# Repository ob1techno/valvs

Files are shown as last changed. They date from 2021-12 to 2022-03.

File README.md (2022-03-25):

# Vālvs
A cascading quad tube VCA module in Eurorack format (3U/32hp).

Vālvs provides four gnarly tube VCAs with drive, gain, feedback, and adjustable, switchable distortion controls.

Vālvs’ outputs are daisy-chained, allowing adjacent groups of 2, 3, or all 4 channels to be mixed together.

Vālvs v1.01 Stealth Mode

Based on/inspired by the work of [Ken Stone](https://www.elby-designs.com/webtek/cgs/cgs65/cgs65_vca.html), [L-1](http://l-1.su/TubeVCA.html) and [Émilie Gillet](https://mutable-instruments.net/modules/veils/), using NOS Soviet 1Ж24Б tubes; as used in the Спутник 1 satellite and Восток 1 spacecraft!

## Demos
#### Single channel audio demo
Vālvs - Quad Tube VCA - Single channel audio demo (https://www.youtube.com/watch?v=XpYaYiyOpng "Vālvs - Quad Tube VCA - Single channel audio demo")

#### Mixer demo
Vālvs - Quad Tube VCA - Mixer demo (https://www.youtube.com/watch?v=zRkru6GmQA4 "Vālvs - Quad Tube VCA - Mixer demo")

## [Build Guide](https://github.com/ob1techno/valvs/wiki/Vālvs-Build-Guide) 
The [build guide](https://github.com/ob1techno/valvs/wiki/Vālvs-Build-Guide) is available [in the wiki](https://github.com/ob1techno/valvs/wiki/Vālvs-Build-Guide).

## Notes

### Calibration/Adjustment
There are no hard and fast rules here. The module is intended to be pretty flexible in terms of gain/distortion so it's very much a case of setting it up to your own taste. You could calibrate each of the 4 VCAs as closely as possible to each other to keep things consistent or you could set each up to have a different character/flavour. 

Each VCA has 4 trimmers on the back of the PCB:

- Plate; this adjusts the plate resistance between 8.2k and 28.2k, which affects the overall gain of the VCA
- CV Init; this adjusts the initial gain voltage, which can be trimmed to ensure the VCA closes completely
- Clean; adjusts the amount of distortion for the "Clean" mode ("Clean" is a relative term in this case)
- Dist; adjusts the amount of distortion for the "Dirty" mode

It's _fairly_ important to get the CV Init trimmed correctly to avoid any audible bleed, but other than that, it's down to taste. You shoud be aware that with additional gain/distortion, there will be inevitable additional noise, so experiment to find the sweet spots.

### Noise
This is inherently a pretty noisy circuit. The tubes can be a little microphonic (this can be improved a little by mounting with some foam/padding between tube and board). The LEDs in Ken Stone's original design injected some more noise as they were connected to the tube's cathode which is in the signal path. L-1's design removes the LEDs, replacing with a 1/2W resistor to ground. 

I've built the circuit both ways and L-1's design is definitely less noisy. I originally thought I preferred the sound with the LEDs, but with all four VCAs mixed, the noise is too noticable, so I've gone with a resistor to ground! I've kept the LEDs to light the tubes, but these are now powered separately, away from the signal path. Even so, these are still quite noisy VCAs, though I prefer the term characterful!

### KiCad Components

I used some KiCad components/footprints that you might need to install if you want to edit the PCB files. You can find those here:
- [EuroCad](https://github.com/nebs/eurocad)
- [E-Switch](https://www.snapeda.com/parts/100SP1T1B4M2QE/E-Switch/view-part/)

### Parts/Construction
I selected parts for this module based on several factors; what I had in stock already, parts I am familiar with and like to use, availability, etc. This means it may not be the easiest module for some to build. For example, I've used 0603 passives, where I could probably have fit a larger size, or used through-hole components. I made this decision because I have a large stock of 0603 passives and I personally prefer SMT to THT. That said, I don't think this is a difficult build. I've built a few of them and it's a relatively low part count per VCA, so quite quick to put together. The surface mount components used also make this suitable for SMD fabrication/assembly services, which I have used successfully on my latest builds.

The construction should all be self explanatory as it's just a single board. Parts go on the side where their silkscreen is (although if you used particularly tall film box caps, you might need to move them to the back). 

There's also the option of mounting the trimmers for the clean/dirty distortion on the front of the PCB and drilling holes so they're adjustable from the front, if you like that sort of thing. 

It's worth using some heatshrink on the tube legs for peace of mind, though not strictly necessary, and I like to use some acetate sheet to fill the windows in case of dust, stray cables, etc.

[There are some build photos in the wiki.](https://github.com/ob1techno/valvs/wiki/Vālvs-Build-Guide)

### Disclaimer
I am not an electronic engineer. I am a musician/programmer with a keen interest in synthesis and electronics. I am entirely self-taught; this was my first project using KiCad and I'm sure I have made many mistakes. 

I have tried to ensure that this works before publishing my work, but this is presented as-is and with no guarantees or acceptance of responsibility on my part. I'd welcome any feedback and I am interested in improving the design; please use the issues section or submit a pull request. 

I also make no promises to support this project, but do get in touch and I'll help if I can.

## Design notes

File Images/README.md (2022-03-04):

## Images

### "OG" unit

Vālvs v1.01 Front

---

### "Stealth" unit

Vālvs v1.01 Stealth Mode

---

### Panel design

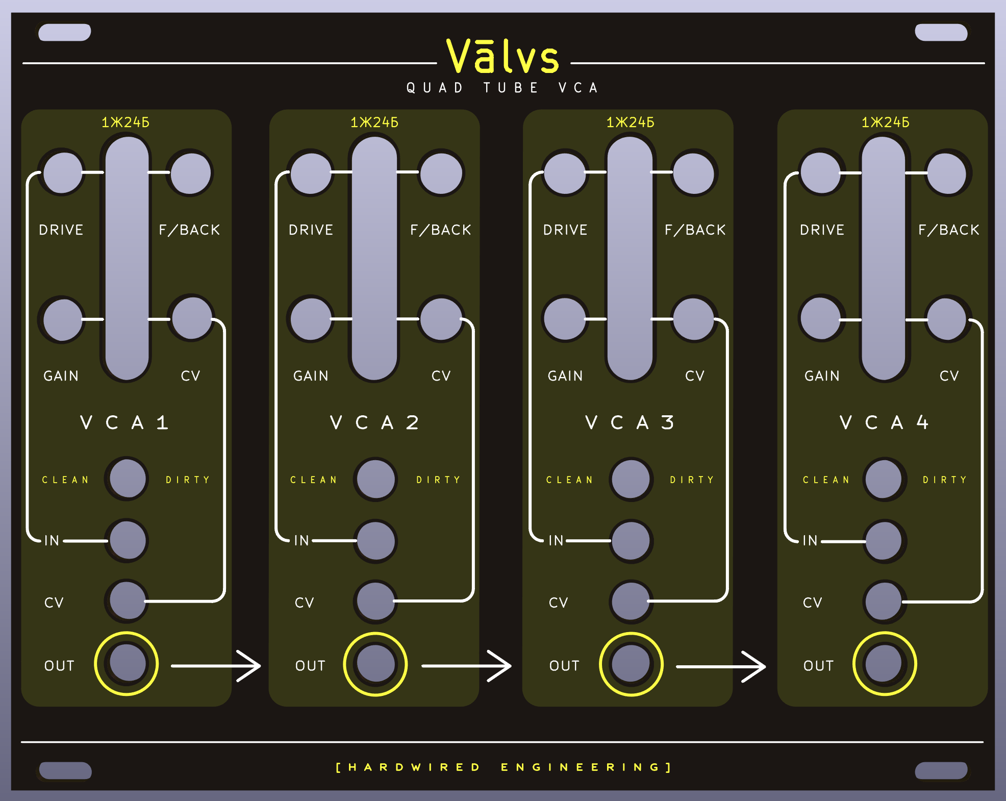
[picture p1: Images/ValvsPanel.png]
Prototype Panel


---

### PCB front 

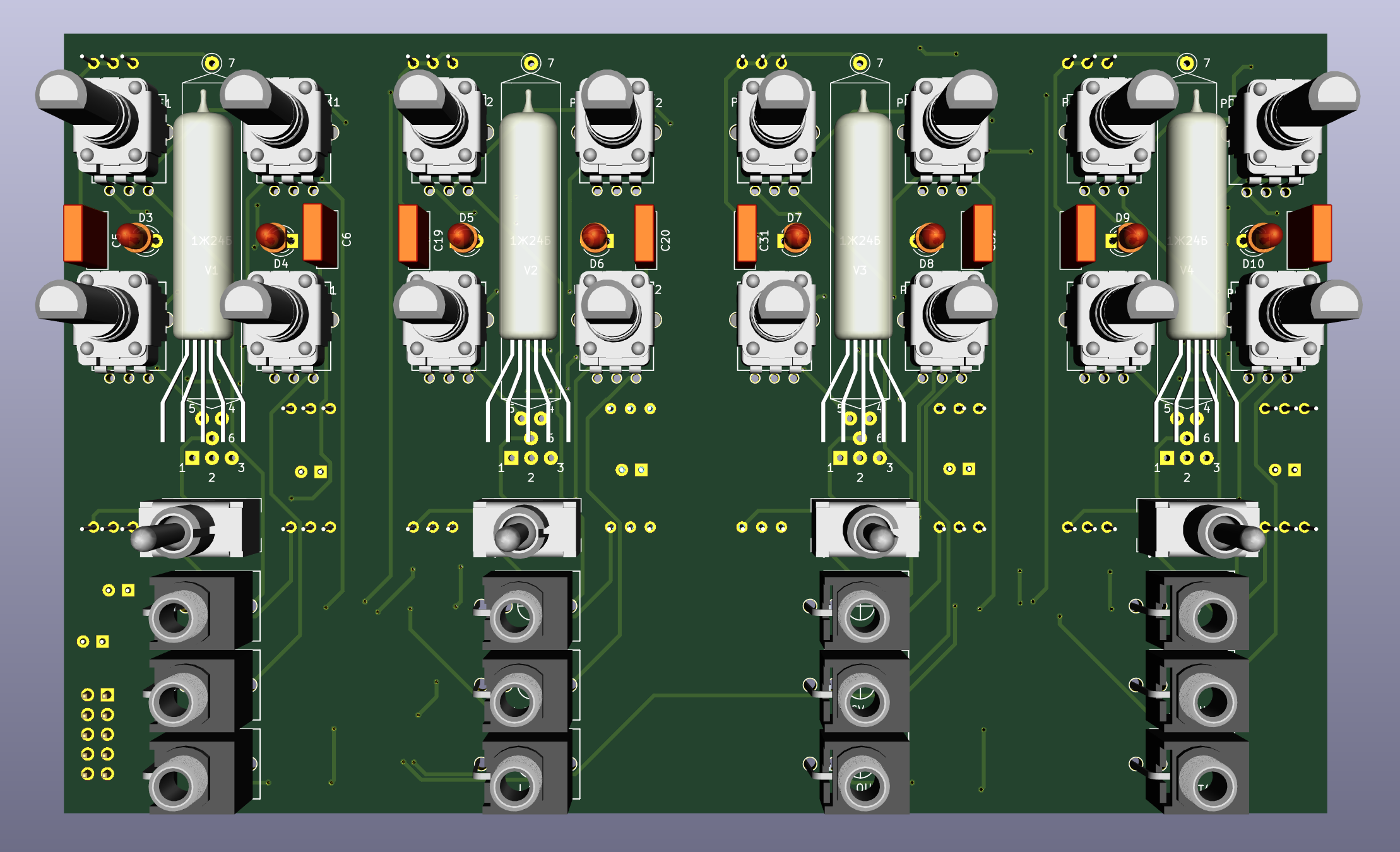
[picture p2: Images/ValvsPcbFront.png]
Prototype PCB Front


N.B. - an incorrect 3D model has been used for the tubes here as I couldn't find the right one!

---

### PCB rear

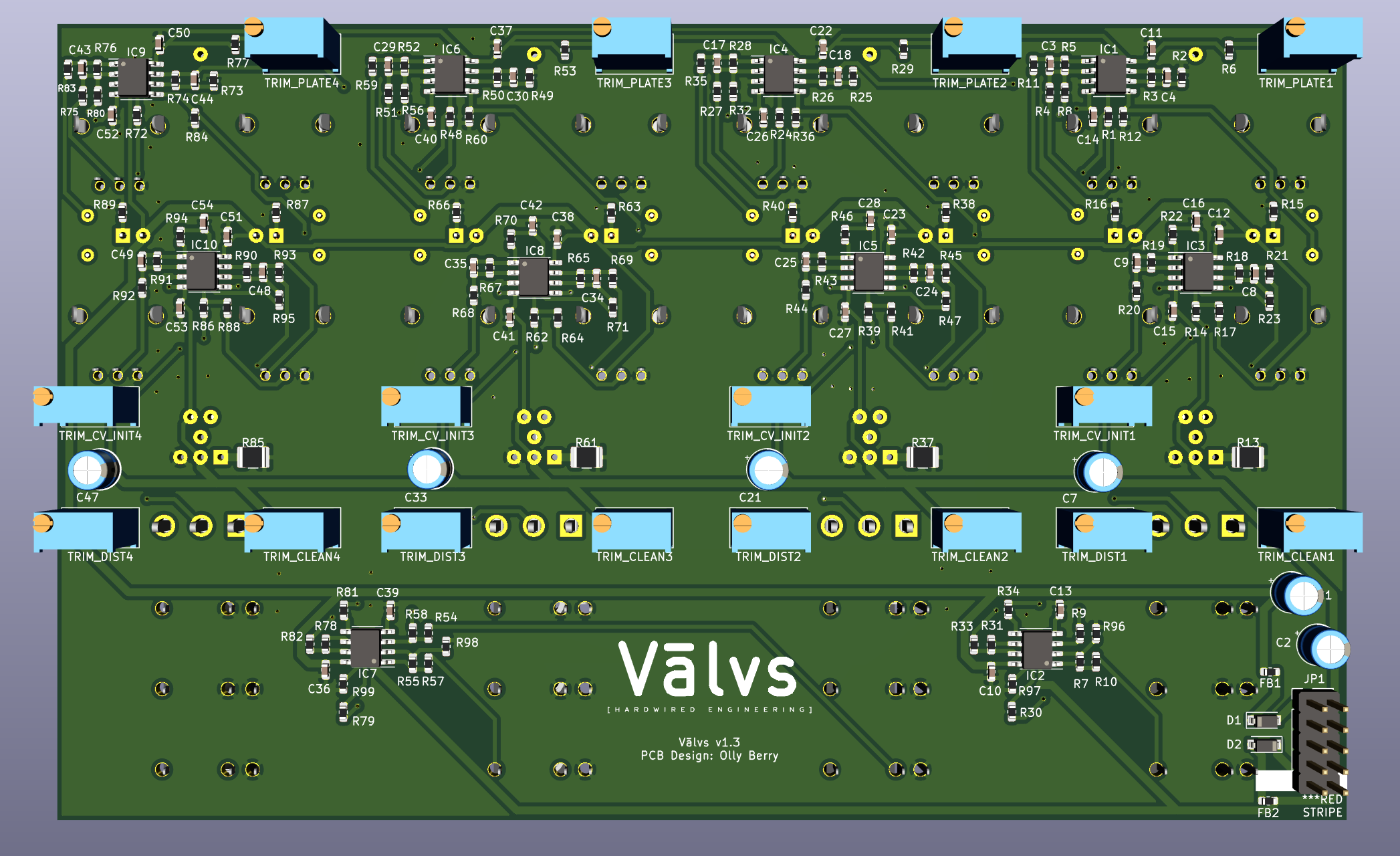
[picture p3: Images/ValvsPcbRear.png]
Prototype PCB Rear


---

### v1.01 build

Vālvs v1.01 Rear

---

### v0.7 prototype build

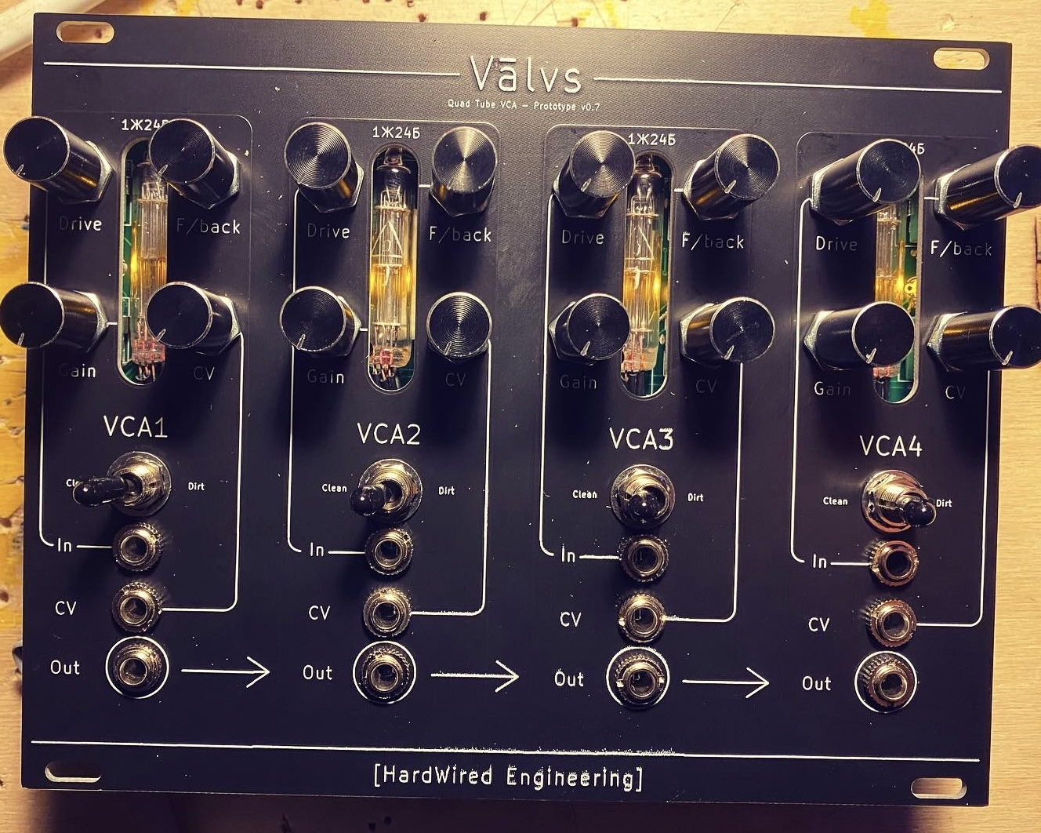
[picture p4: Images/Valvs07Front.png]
Prototype v0.7 Build


Prototype v0.7 Build

---

### v0.3 prototype build

Prototype v0.3 Build

Prototype v0.3 Build

---

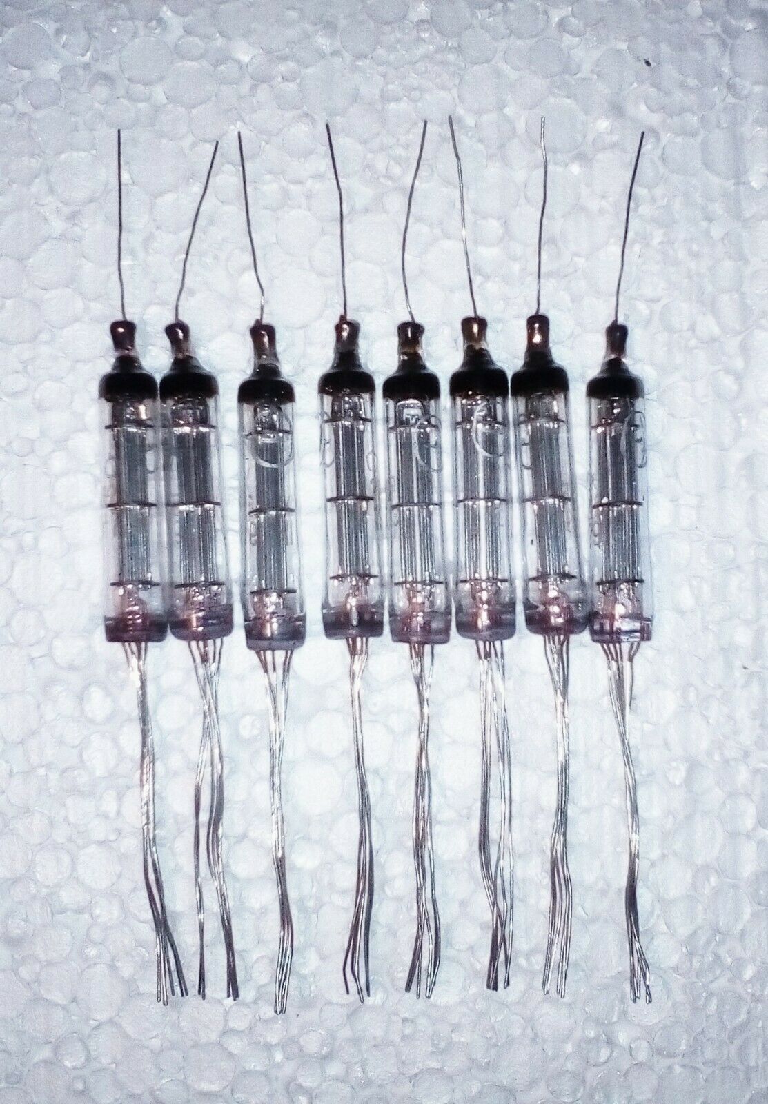
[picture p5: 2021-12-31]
Images/s-l1600.jpg

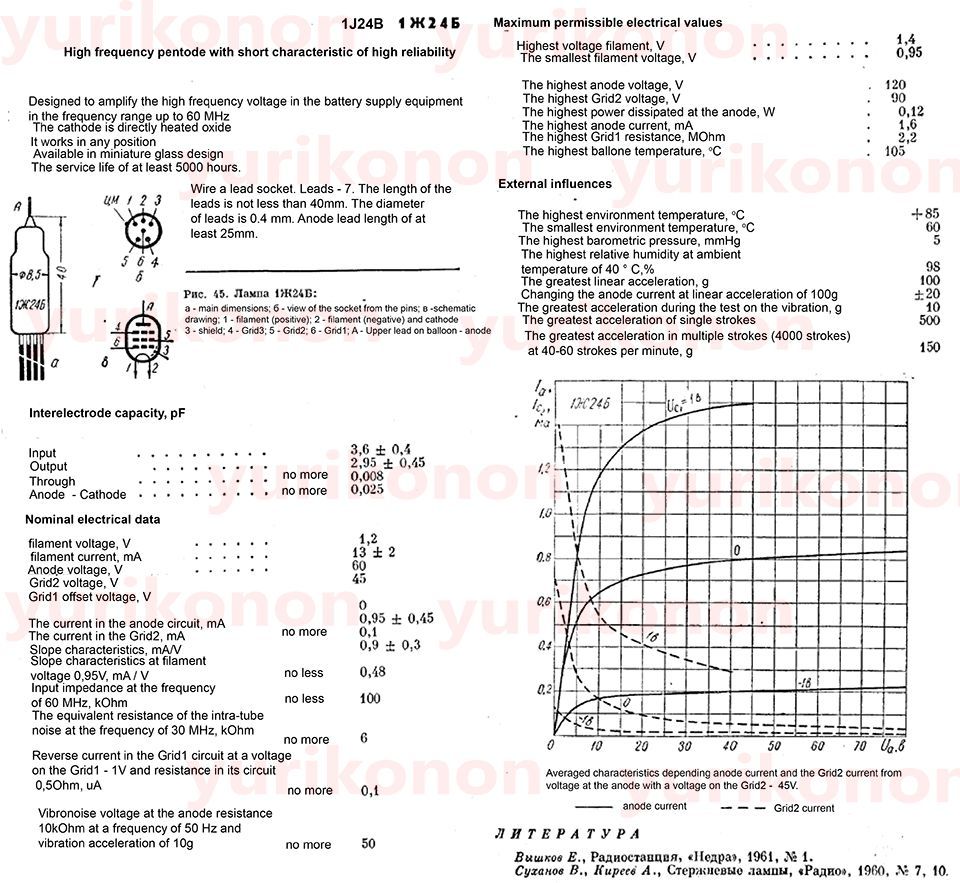
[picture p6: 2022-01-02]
Images/1J24b Data.jpg

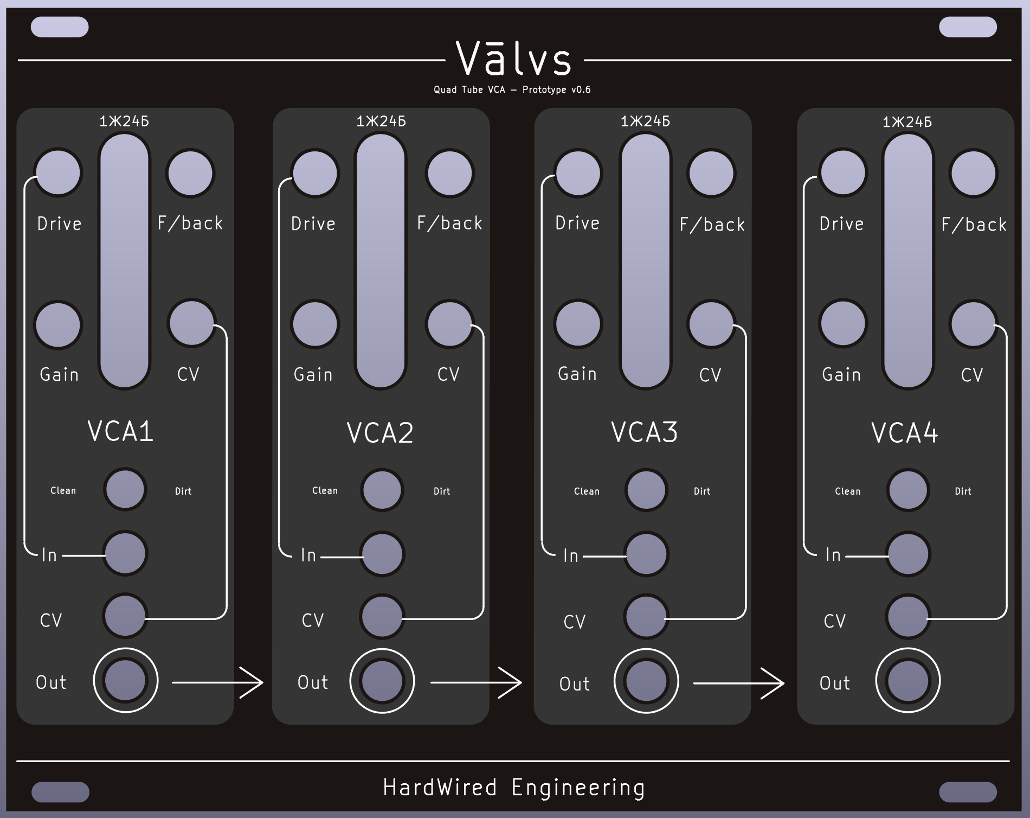
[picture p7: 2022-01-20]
Images/_ValvsPanel.png

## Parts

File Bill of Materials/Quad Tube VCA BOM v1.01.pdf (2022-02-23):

### Vālvs - Quad Tube VCA v1.01

Designator | Quantity | Value | Package | Supplier and ref | Notes
V2,V1,V4,V3 | 4 | 1Ж24Б/1J24B | Valve_Mini_Pentode_1j24b | https://www.ebay.co.uk | Lots of suppliers on eBay - be prepared to wait a long time for Russian post!
IC10,IC8,IC5,IC3 | 4 | LM358 | SOIC-8_3.9x4.9mm_P1.27mm | https://www.mouser.co.uk/ProductDetail/Texas-Instruments/LM358DR?qs=Zu35EjizYSSY6pJ37yj mHA%3D%3D (https://www.mouser.co.uk/ProductDetail/Texas-Instruments/LM358DR?qs=Zu35EjizYSSY6pJ37yjmHA%3D%3D) | Do not sub for another type, the characteristics of LM358 are required.
IC9,IC1,IC7,IC2,IC6,IC4 | 6 | TL072 | SOIC-8_3.9x4.9mm_P1.27mm | https://www.mouser.co.uk/ProductDetail/STMicroelectronics/TL072CDT?qs=6fffrORWf5pLFxBvwrM MAA%3D%3D (https://www.mouser.co.uk/ProductDetail/STMicroelectronics/TL072CDT?qs=6fffrORWf5pLFxBvwrMMAA%3D%3D) | Can be subbed for any similar/better op amp with the same pinout.
D1,D2 | 2 | 1N5819 | D_SOD-123 | https://www.mouser.co.uk/ProductDetail/Diodes-Incorporated/1N5819HW-7-F?qs=NQ47qNm99eDyWTEd 07miYA%3D%3D (https://www.mouser.co.uk/ProductDetail/Diodes-Incorporated/1N5819HW-7-F?qs=NQ47qNm99eDyWTEd07miYA%3D%3D) | Any Schottky/rectifier diode is fine.
D10,D9,D8,D7,D6,D5,D4,D3 | 8 | LED | LED_D3.0mm | https://www.mouser.co.uk/ProductDetail/Kingbright/WP3A8YD?qs=DkZGzo4b%252BTKV dEGNaCX1PA%3D%3D (https://www.mouser.co.uk/ProductDetail/Kingbright/WP3A8YD?qs=DkZGzo4b%252BTKVdEGNaCX1PA%3D%3D) | You can use any colour here - the voltage drop isn’t important and it doesn’t affect the sound adjust the current limiting resistors to control brightness.
C47,C33,C21,C7 | 4 | 47uf | CP_Radial_D5.0mm_P2.50mm | https://www.mouser.co.uk/ProductDetail/Nichicon/UVR1E470MDD1TD?qs=nd5JBRjZIXjuiqeEq8Mr 7A%3D%3D (https://www.mouser.co.uk/ProductDetail/Nichicon/UVR1E470MDD1TD?qs=nd5JBRjZIXjuiqeEq8Mr7A%3D%3D) | Standard elcos.
C2,C1 | 2 | 10uf | CP_Radial_D5.0mm_P2.50mm | https://www.mouser.co.uk/ProductDetail/Panasonic/EEU-EB1H100SH?qs=MtOUKumLmnaxYZkjn KwzWw%3D%3D (https://www.mouser.co.uk/ProductDetail/Panasonic/EEU-EB1H100SH?qs=MtOUKumLmnaxYZkjnKwzWw%3D%3D) | Standard elcos - for power filtering, so value isn’t too important.
C46,C45,C32,C31,C20,C19,C6,C5 | 8 | 470nf | C_Rect_L7.2mm_W2.5mm_P5.00mm_FK S2_FKP2_MKS2_MKP2 | https://www.mouser.co.uk/ProductDetail/WIMA/MKS2C034701C00JI00?qs=sJjjjplDs9sFUTxfzw%2 FiOA%3D%3D (https://www.mouser.co.uk/ProductDetail/WIMA/MKS2C034701C00JI00?qs=sJjjjplDs9sFUTxfzw%2FiOA%3D%3D) | Use any good quality audio grade film caps here, e.g. WIMA MKS2
C39,C36,C13,C10,C54,C53,C52,C51,C50,C42,C41,C40 ,C38,C37,C28,C27,C26,C23,C22,C16,C15,C14,C12,C1 1 | 24 | 100nf | C_0603_1608Metric | https://www.mouser.co.uk/ProductDetail/KEMET/C0603C104J5RACTU?qs=sGAEpiMZZMvsSlwiRh F8qiamir66WTSk12y6gsd Y7%252BI%3D (https://www.mouser.co.uk/ProductDetail/KEMET/C0603C104J5RACTU) | Just 0603 MLCCs -brand, etc is not important.
C49,C48,C44,C43,C35,C34,C30,C29,C25,C24,C18,C17 ,C9,C8,C4,C3 | 16 | 47pf | C_0603_1608Metric | https://www.mouser.co.uk/ProductDetail/KEMET/C0603C470J5GACTU?qs=sGAEpiMZZMvsSlwiRh F8qtArWTegJmVHgSUES6 bCM%2Fw%3D (https://www.mouser.co.uk/ProductDetail/KEMET/C0603C470J5GACTU) | Just 0603 MLCCs -brand, etc is not important.
R85,R61,R37,R13 | 4 | 750R | R_1206_3216Metric | https://www.mouser.co.uk/ProductDetail/YAGEO/RC1206FR-7W750RL?qs=f6khj2Jg0Fg0cazhuva %252BDQ%3D%3D (https://www.mouser.co.uk/ProductDetail/YAGEO/RC1206FR-7W750RL?qs=f6khj2Jg0Fg0cazhuva%252BDQ%3D%3D) | 1206 - at least 0.5W
R91,R90,R67,R65,R43,R42,R19,R18 | 8 | 220k | R_0603_1608Metric | https://www.mouser.co.uk/ProductDetail/YAGEO/AC0603FR-10220KL?qs=sGAEpiMZZMvdGkrng 054tz1y1XEHv7sNMAnFSv XriNoKizHZKtlSRw%3D% 3D (https://www.mouser.co.uk/ProductDetail/YAGEO/AC0603FR-10220KL) | Just 0603 resistors -brand, etc is not important.
R78,R55,R31,R7,R79,R54,R30,R81,R58,R34,R9,R50,R4 9,R95,R93,R88,R86,R80,R76,R75,R74,R73,R71,R69,R6 4,R62,R56,R52,R51,R47,R45,R41,R39,R32,R28,R27,R2 6,R25,R23,R21,R17,R14,R8,R5,R4,R3,R2 | 47 | 100k | R_0603_1608Metric | https://www.mouser.co.uk/ProductDetail/YAGEO/AC0603FR-07100KL?qs=sGAEpiMZZMvdGkrng 054twUTJTt6Prte8f9Q1fTD 39M%3D (https://www.mouser.co.uk/ProductDetail/YAGEO/AC0603FR-07100KL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) | Just 0603 resistors -brand, etc is not important.
R92,R68,R44,R20 | 4 | 51k | R_0603_1608Metric | https://www.mouser.co.uk/ProductDetail/YAGEO/AC0603FR-0751KL?qs=sGAEpiMZZMvdGkrng 054t2uy2SOblyUPV31m4 GYQ2YY%3D (https://www.mouser.co.uk/ProductDetail/YAGEO/AC0603FR-0751KL?qs=sGAEpiMZZMvdGkrng054t2uy2SOblyUPV31m4GYQ2YY%3D) | Just 0603 resistors -brand, etc is not important.
R84,R60,R36,R12 | 4 | 33k | R_0603_1608Metric | https://www.mouser.co.uk/ProductDetail/YAGEO/RC0603FR-0733KL?qs=sGAEpiMZZMvdGkrng 054t3pr%252BPE%2FADj s1q%2FZ%252BrnSSyk% 3D (https://www.mouser.co.uk/ProductDetail/YAGEO/RC0603FR-0733KL) | Just 0603 resistors -brand, etc is not important.
R94,R70,R46,R22 | 4 | 10k | R_0603_1608Metric | https://www.mouser.co.uk/ProductDetail/YAGEO/RC0603FR-0710KL?qs=sGAEpiMZZMvdGkrng 054t0Ql6vgZwrVhDmPP4 HS%2FwqE%3D (https://www.mouser.co.uk/ProductDetail/YAGEO/RC0603FR-0710KL) | Just 0603 resistors -brand, etc is not important.

1

R77,R53,R29,R6 | 4 | 8k2 | R_0603_1608Metric | https://www.mouser.co.uk/ProductDetail/YAGEO/AC0603FR-078K2L?qs=sGAEpiMZZMvdGkrng 054twVr7TWeaA0s3ovyEr AAXeo%3D (https://www.mouser.co.uk/ProductDetail/YAGEO/AC0603FR-078K2L?qs=sGAEpiMZZMvdGkrng054twVr7TWeaA0s3ovyErAAXeo%3D) | Just 0603 resistors -brand, etc is not important.
R83,R59,R35,R11 | 4 | 2k2 | R_0603_1608Metric | https://www.mouser.co.uk/ProductDetail/YAGEO/AC0603FR-072K2L?qs=sGAEpiMZZMvdGkrng 054t2uy2SOblyUP4r6YZnZ O93Q%3D (https://www.mouser.co.uk/ProductDetail/YAGEO/AC0603FR-072K2L?qs=sGAEpiMZZMvdGkrng054t2uy2SOblyUP4r6YZnZO93Q%3D) | Just 0603 resistors -brand, etc is not important.
R89,R87,R66,R63,R40,R38,R16,R15 | 8 | 1k2 | R_0603_1608Metric | https://www.mouser.co.uk/ProductDetail/YAGEO/AC0603FR-071K2L?qs=sGAEpiMZZMvdGkrng 054twVr7TWeaA0sx2gFaW LcM6A%3D (https://www.mouser.co.uk/ProductDetail/YAGEO/AC0603FR-071K2L?qs=sGAEpiMZZMvdGkrng054twVr7TWeaA0sx2gFaWLcM6A%3D) | Just 0603 resistors -brand, etc is not important.
R72,R48,R24,R1 | 4 | 1k | R_0603_1608Metric | https://www.mouser.co.uk/ProductDetail/YAGEO/AC0603FR-071KL?qs=sGAEpiMZZMvdGkrng 054twUTJTt6Prte5idpC10 RpFA%3D (https://www.mouser.co.uk/ProductDetail/YAGEO/AC0603FR-071KL?qs=sGAEpiMZZMvdGkrng054twUTJTt6Prte5idpC10RpFA%3D) | Just 0603 resistors -brand, etc is not important.
R82,R57,R33,R10 | 4 | 330R | R_0603_1608Metric | https://www.mouser.co.uk/ProductDetail/YAGEO/RC0603FR-07330RL?qs=sGAEpiMZZMvdGkrng 054t3pr%252BPE%2FADj sgbcW32RiNJg%3D (https://www.mouser.co.uk/ProductDetail/YAGEO/RC0603FR-07330RL) | Just 0603 resistors -brand, etc is not important.
POT_IN_DRIVE4,POT_IN_DRIVE3,POT_IN_DRIVE2,POT _IN_DRIVE1,POT_GAIN4,POT_GAIN3,POT_GAIN2,POT _GAIN1,POT_FEEDBACK4,POT_FEEDBACK3,POT_FEE DBACK2,POT_FEEDBACK1 | 12 | A100k | Alpha9mmPot | https://www.thonk.co.uk/product-category/alpha/alpha-9mm-vertical/ (https://www.thonk.co.uk/product-category/alpha/alpha-9mm-vertical/) | Use pots that attach to the panel, not the trimmer type, as the nuts hold the panel on! Don’t forget knobs!
POT_CV_LEVEL4,POT_CV_LEVEL3,POT_CV_LEVEL2,P OT_CV_LEVEL1 | 4 | B100k | Alpha9mmPot | https://www.thonk.co.uk/product-category/alpha/alpha-9mm-vertical/ (https://www.thonk.co.uk/product-category/alpha/alpha-9mm-vertical/) | Use pots that attach to the panel, not the trimmer type, as the nuts hold the panel on! Don’t forget knobs!
J_OUT4,J_OUT3,J_OUT2,J_OUT1,J_IN4,J_IN3,J_IN2,J _IN1,J_CV_IN4,J_CV_IN3,J_CV_IN2,J_CV_IN1 | 12 | Thonkiconn | PJ301M-12 | https://www.thonk.co.uk/shop/thonkiconn/ (https://www.thonk.co.uk/shop/thonkiconn/) | Don’t forget nuts!
TRIM_DIST4,TRIM_DIST3,TRIM_DIST2,TRIM_DIST1 | 4 | 1M | Potentiometer_Bourns_3296W_Vertical | https://www.thonk.co.uk/shop/25-turn-trimmer-potentiometer/ (https://www.thonk.co.uk/shop/25-turn-trimmer-potentiometer/) | DIST - Adjust to trim the amount of distortion for the dirty setting.
TRIM_CV_INIT4,TRIM_CV_INIT3,TRIM_CV_INIT2,TRIM_ CV_INIT1,TRIM_CLEAN4,TRIM_CLEAN3,TRIM_CLEAN2 ,TRIM_CLEAN1 | 8 | 100k | Potentiometer_Bourns_3296W_Vertical | https://www.thonk.co.uk/shop/25-turn-trimmer-potentiometer/ (https://www.thonk.co.uk/shop/25-turn-trimmer-potentiometer/) | CV INIT - Adjust to trim the initial CV amount to ensure the VCA closes fully. CLEAN - Adjust to trim the amount of distortion for the clean setting.
TRIM_PLATE4,TRIM_PLATE3,TRIM_PLATE2,TRIM_PLA TE1 | 4 | 20k | Potentiometer_Bourns_3296W_Vertical | https://www.thonk.co.uk/shop/25-turn-trimmer-potentiometer/ (https://www.thonk.co.uk/shop/25-turn-trimmer-potentiometer/) | PLATE - Adjust to trim the plate voltage for more/ less overall gain.
SW_DIST1,SW_DIST2,SW_DIST3,SW_DIST4 | 4 | SW_SPDT | SW_100SP1T1B4M2QE | https://www.thonk.co.uk/shop/mini-toggle-switches/ (https://www.thonk.co.uk/shop/mini-toggle-switches/) | SPDT ON-ON. Miniature (NOT sub-miniature) toggle switch with solder pins (lugs won’t fit).
JP1 | 1 | EURO_PWR_2x5 | PinHeader_2x05_P2.54mm_Vertical | https://www.ebay.co.uk/sch/i.html?_from=R40&_trksid=p2380057.m570.l1313&_nkw=arduino+headers&_sacat=0 (https://www.ebay.co.uk/sch/i.html?_from=R40&_nkw=arduino+headers&_sacat=0) | Just use standard pin header strips. There *might* be room for a shrouded header, I have’t tried.
FB2,FB1 | 2 | Ferrite | R_0603_1608Metric | https://www.mouser.co.uk/ProductDetail/TDK/MMZ1608D100CTAH0?qs=sGAEpiMZZMt1hubY8 0%2Fs8NxD%2FRHPQm5 hFzPldG0m4y4c5F3mTa3n VA%3D%3D (https://www.mouser.co.uk/ProductDetail/TDK/MMZ1608D100CTAH0) | Just don’t, I know, alright!

2

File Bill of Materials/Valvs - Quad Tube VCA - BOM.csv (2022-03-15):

Comment | Designator | Footprint | LCSC
10uf | C1,C2 | Capacitor_THT:CP_Radial_D5.0mm_P2.50mm
100nf | C10,C11,C12,C13,C14,C15,C16,C22,C23,C26,C27,C28,C36,C37,C38,C39,C40,C41,C42,C50,C51,C52,C53,C54 | Capacitor_SMD:C_0603_1608Metric
470nf | C5,C6,C19,C20,C31,C32,C45,C46 | Capacitor_THT:C_Rect_L7.2mm_W2.5mm_P5.00mm_FKS2_FKP2_MKS2_MKP2
47uf | C7,C21,C33,C47 | Capacitor_THT:CP_Radial_D5.0mm_P2.50mm
47pf | C3,C4,C8,C9,C17,C18,C24,C25,C29,C30,C34,C35,C43,C44,C48,C49 | Capacitor_SMD:C_0603_1608Metric
1N5819 | D1,D2 | Diode_SMD:D_SOD-123
LED | D3,D4,D5,D6,D7,D8,D9,D10 | LED_THT:LED_D3.0mm
Ferrite | FB1,FB2 | Resistor_SMD:R_0603_1608Metric
LM358 | IC3,IC5,IC8,IC10 | Package_SO:SOIC-8_3.9x4.9mm_P1.27mm
TL072 | IC1,IC2,IC4,IC6,IC7,IC9 | Package_SO:SOIC-8_3.9x4.9mm_P1.27mm
EURO_PWR_2x5 | JP1 | Connector_PinHeader_2.54mm:PinHeader_2x05_P2.54mm_Vertical
PJ301M-12 | J_OUT1,J_CV_IN1,J_IN1,J_IN2,J_CV_IN2,J_OUT2,J_OUT3,J_CV_IN3,J_IN3,J_CV_IN4,J_IN4,J_OUT4 | Eurocad:PJ301M-12
B100k | POT_CV_LEVEL1,POT_CV_LEVEL2,POT_CV_LEVEL3,POT_CV_LEVEL4 | Eurocad:Alpha9mmPot
A100k | POT_GAIN1,POT_IN_DRIVE1,POT_FEEDBACK1,POT_FEEDBACK2,POT_IN_DRIVE2,POT_GAIN2,POT_GAIN3,POT_IN_DRIVE3,POT_FEEDBACK3,POT_GAIN4,POT_IN_DRIVE4,POT_FEEDBACK4 | Eurocad:Alpha9mmPot
1k | R1,R24,R48,R72 | Resistor_SMD:R_0603_1608Metric
330R | R10,R33,R57,R82 | Resistor_SMD:R_0603_1608Metric
2k2 | R11,R35,R59,R83 | Resistor_SMD:R_0603_1608Metric
33k | R2,R12,R25,R36,R49,R60,R73,R84 | Resistor_SMD:R_0603_1608Metric
220k | R18,R19,R42,R43,R65,R67,R90,R91 | Resistor_SMD:R_0603_1608Metric
51k | R20,R44,R68,R92 | Resistor_SMD:R_0603_1608Metric
100k | R3,R4,R5,R8,R9,R14,R17,R21,R23,R26,R27,R28,R30,R31,R32,R34,R39,R41,R45,R47,R50,R51,R52,R54,R55,R56,R58,R62,R64,R69,R71,R74,R75,R76,R78,R79,R80,R81,R86,R88,R93,R95,R96,R97,R98,R99 | Resistor_SMD:R_0603_1608Metric
10k | R22,R46,R70,R94 | Resistor_SMD:R_0603_1608Metric
1k2 | R15,R16,R38,R40,R63,R66,R87,R89 | Resistor_SMD:R_0603_1608Metric
8k2 | R6,R29,R53,R77 | Resistor_SMD:R_0603_1608Metric
100R | R7 | Resistor_SMD:R_0603_1608Metric
750R | R13,R37,R61,R85 | Resistor_SMD:R_1210_3225Metric
SW_SPDT | SW_DIST1,SW_DIST2,SW_DIST3,SW_DIST4 | 100SP1T1B4M2QE:SW_100SP1T1B4M2QE
100k | TRIM_CV_INIT1,TRIM_CLEAN1,TRIM_CLEAN2,TRIM_CV_INIT2,TRIM_CV_INIT3,TRIM_CLEAN3,TRIM_CV_INIT4,TRIM_CLEAN4 | Potentiometer_THT:Potentiometer_Bourns_3296W_Vertical
1M | TRIM_DIST1,TRIM_DIST2,TRIM_DIST3,TRIM_DIST4 | Potentiometer_THT:Potentiometer_Bourns_3296W_Vertical
20k | TRIM_PLATE1,TRIM_PLATE2,TRIM_PLATE3,TRIM_PLATE4 | Potentiometer_THT:Potentiometer_Bourns_3296W_Vertical
1J24B | V1,V2,V3,V4 | Valve:Valve_Mini_Pentode_1j24b

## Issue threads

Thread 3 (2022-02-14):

Missing supplier link in BOM

ob1techno, 2022-02-14:
The v1.01 BOM is missing a supplier (Mouser) link for the 750R 1/2W resistors.

Closed 2022-02-23.

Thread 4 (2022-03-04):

Cascaded signals need to be inverted.

ob1techno, 2022-03-04:
Needs an op-amp inverter stage.

Closed 2022-03-04.

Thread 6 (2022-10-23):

LED Polarity?

lnikj, 2022-10-23:
Hi. There is no indication on the PCB of the LED polarity. Cathode in square or round?
This is the black PCB supplied by Pusherman.

lnikj, 2022-10-23:
Cathode = square.

Closed 2022-10-23.

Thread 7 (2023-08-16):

Having issue with high background noise that seems to depend on other LEDS/screens in other modules

Testbild-synth, 2023-08-16:
so I've built the module half a year ago and but haven't tested it extensively or even calibrated it really. Now today I set up a new rack and tested everything. On my unit, there seems to be an issue with very noticeable background noise that seems to depend on the other modules connected to the same PSU/near it. Specifically, when I unplug modules with oled screens and modules that have many LEDs, the background noise is considerably less.
I never noticed this in my old rack, might have been there already though since I didn't get to use the module much until now.
Do you think this could be caused by the power supply being strained (my new rack has a relatively small PSU for it's size), some RF thing or the tuning/calibration of the unit?

lookitsgraphic, 2024-02-21:
This is not necessarily due to the power supply, in the event of an undersized power supply, certain modules risk freezing or showing other symptoms.
On the other hand, many modules using tubes capture the noise of modules using I2C OLED screens and LED displays. The best is to put the digital modules on one power supply and the digital modules on another.

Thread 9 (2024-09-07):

10K trimmers or 100K ?

BBGuy, 2024-09-07:
Hi, Just sorted out the parts of a full kit from Pusherman and noticed that it had trimmers labelled 103 (10K) instead of the 100K in the BOM. Wanted to make sure these are ok before sticking them in :)
So so looking forward to having this built.
Thanks for what will surely be an amazing module.

BBGuy, 2024-09-09:
Finished building and works with no issues using the 10K. This thing is so good. I don't know how I managed with out it :)
Worth updating the BOM with a commit msg explaining the change.

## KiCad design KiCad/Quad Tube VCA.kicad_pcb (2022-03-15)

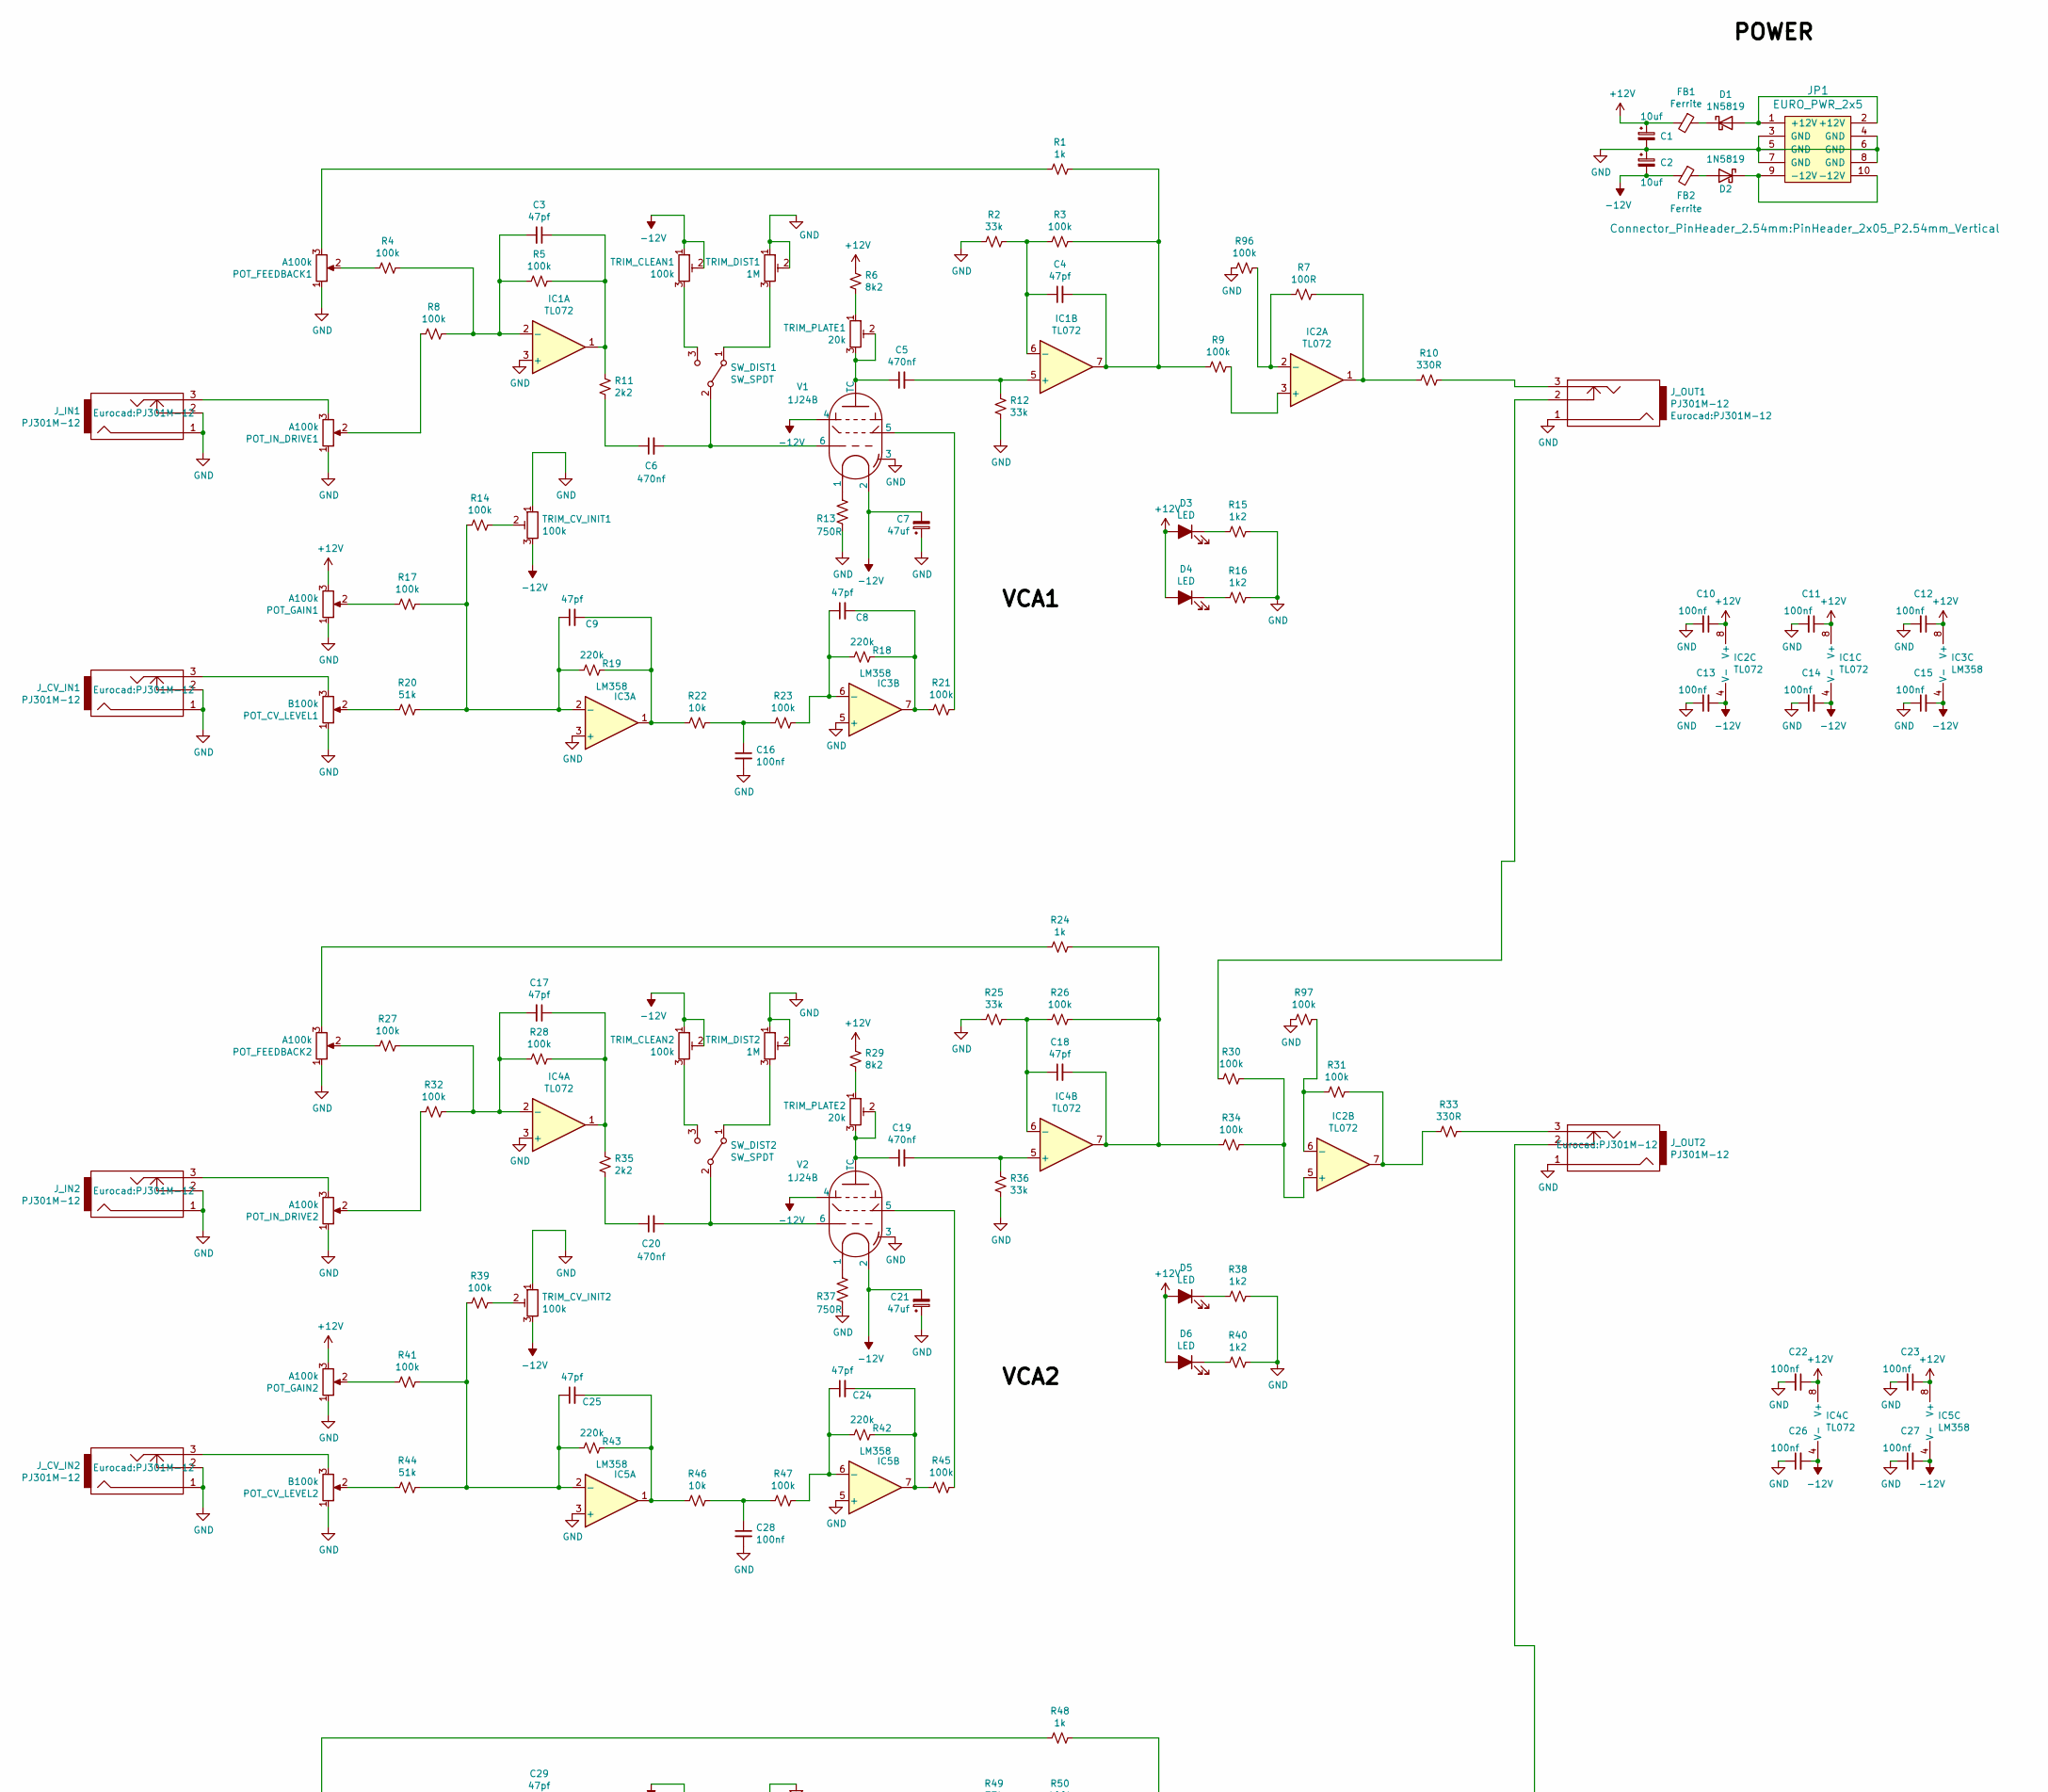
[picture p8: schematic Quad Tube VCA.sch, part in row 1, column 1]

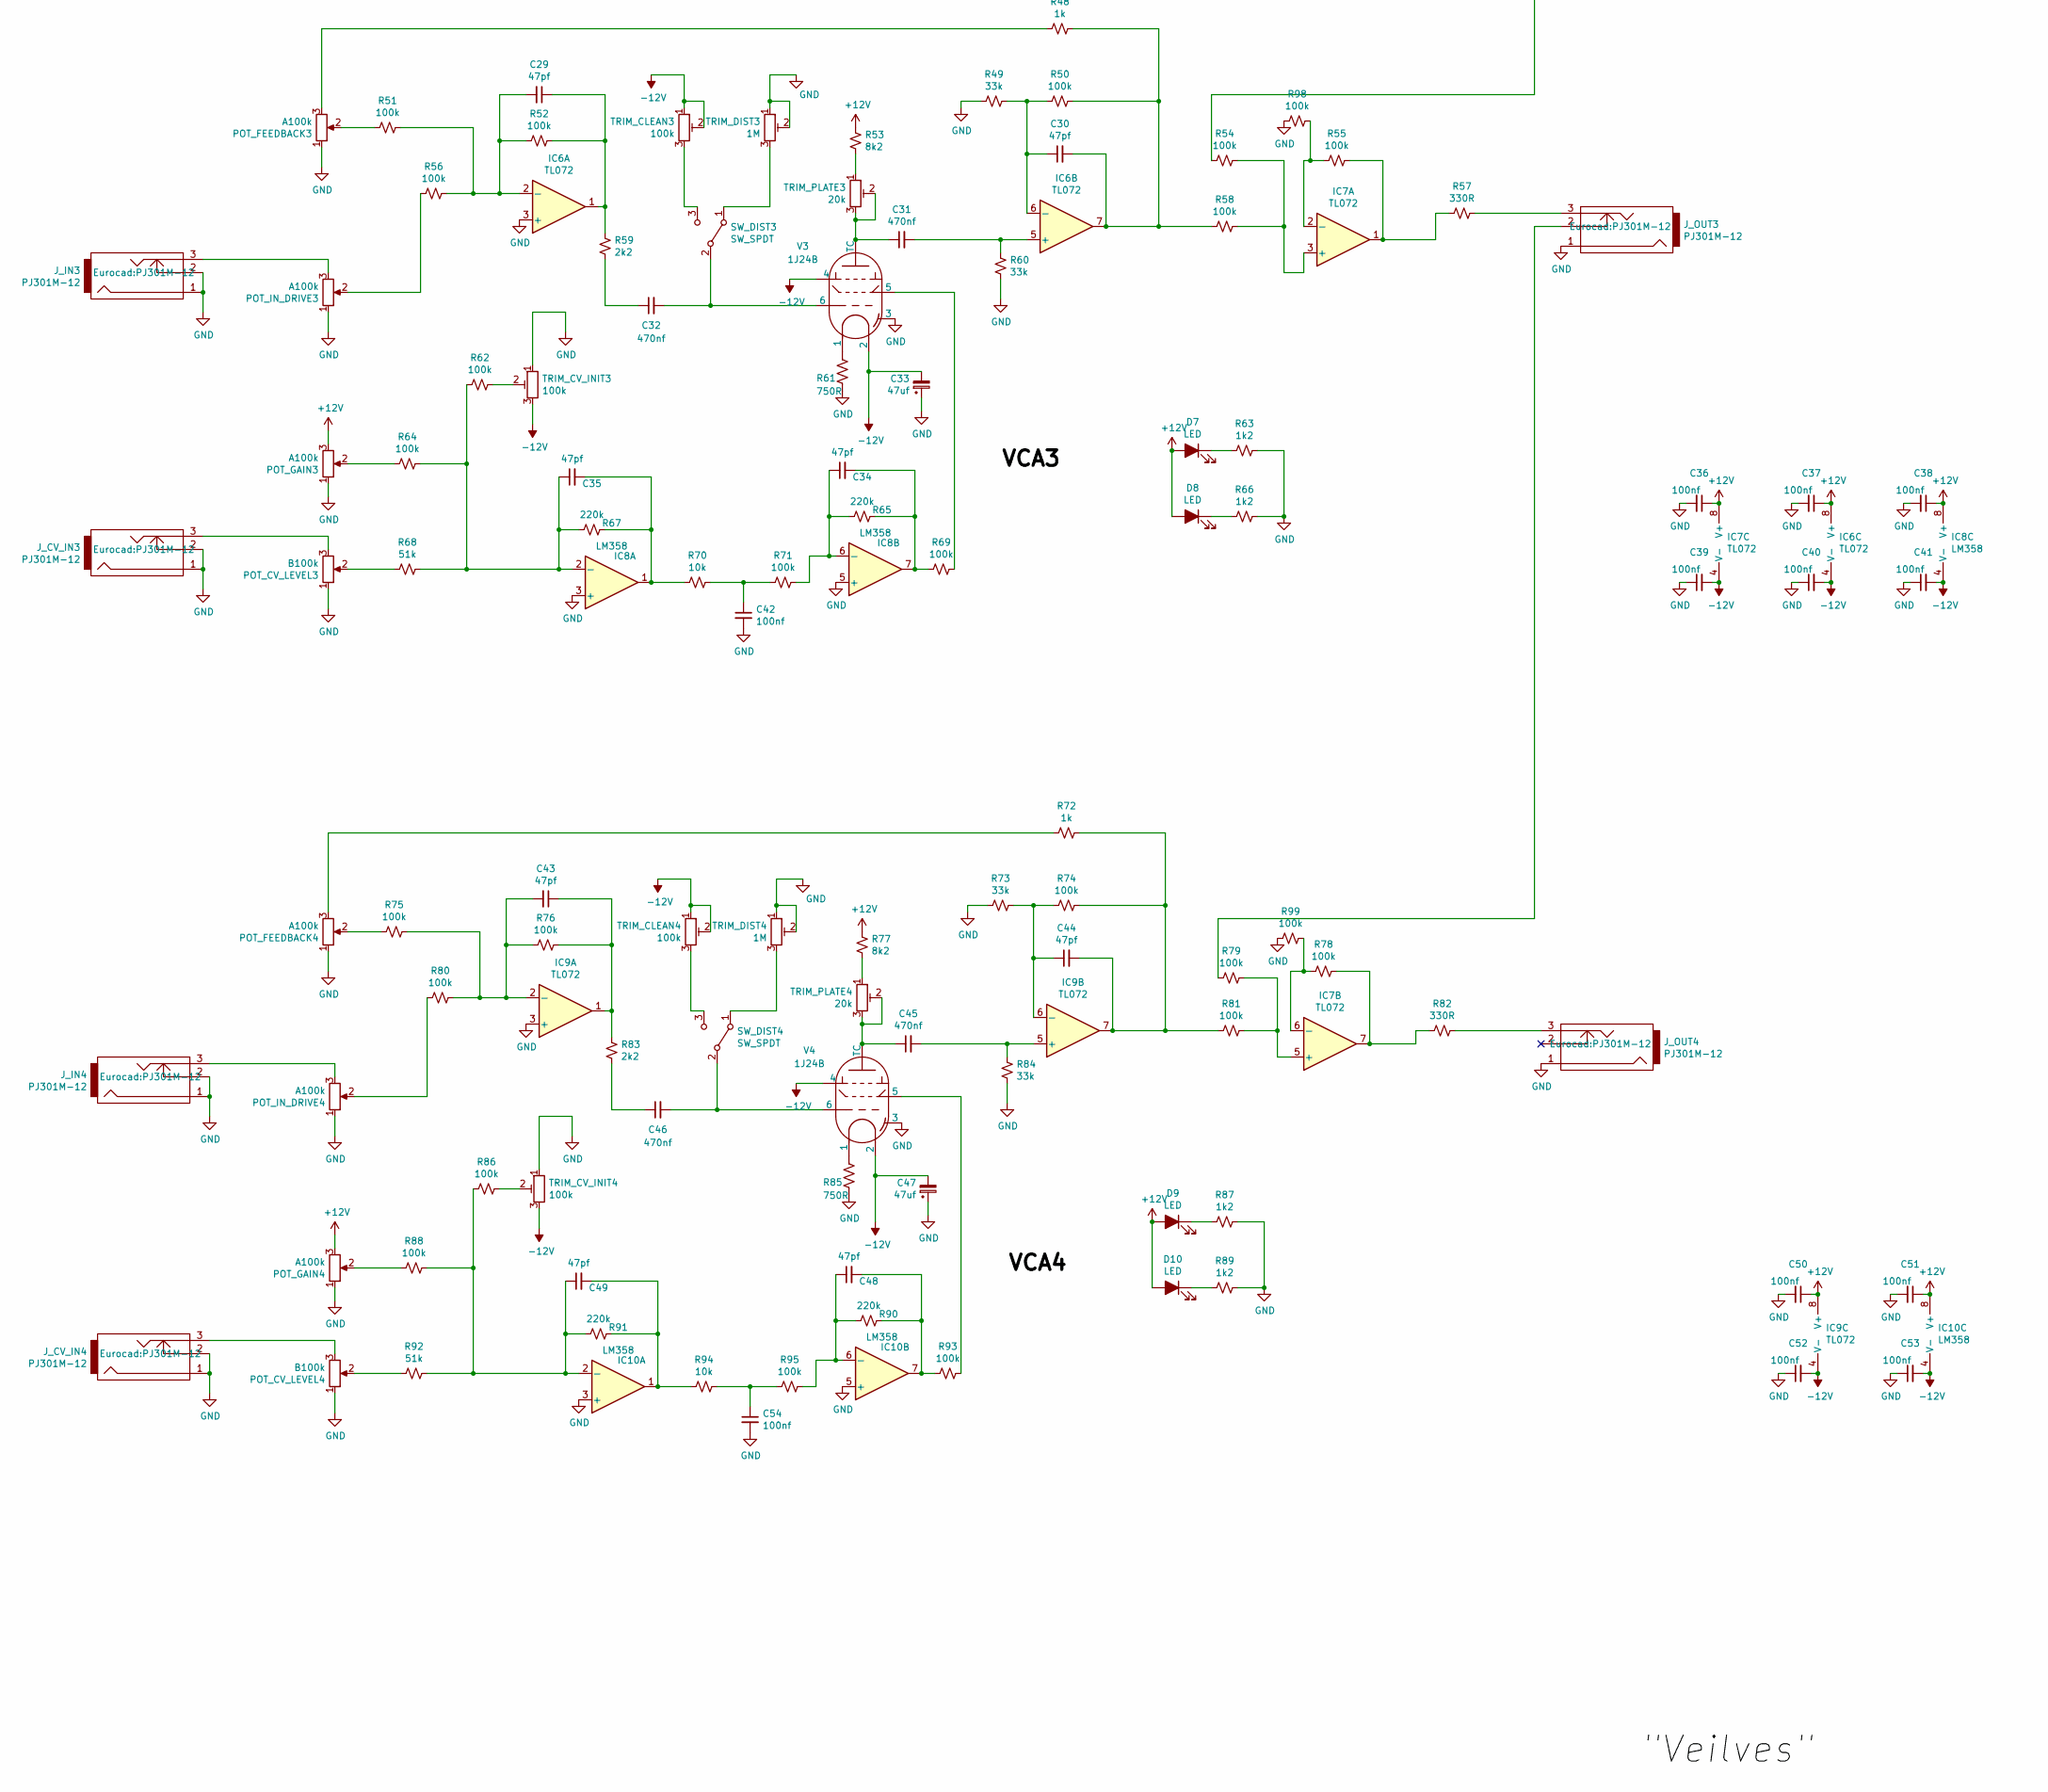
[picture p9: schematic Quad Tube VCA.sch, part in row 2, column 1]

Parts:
C1, C2: 10uf; CP_Radial_D5.0mm_P2.50mm
C3, C4, C8, C9, C17, C18, C24, C25, C29, C30, C34, C35, C43, C44, C48, C49: 47pf; C_0603_1608Metric
C5, C6, C19, C20, C31, C32, C45, C46: 470nf; C_Rect_L7.2mm_W2.5mm_P5.00mm_FKS2_FKP2_MKS2_MKP2
C7, C21, C33, C47: 47uf; CP_Radial_D5.0mm_P2.50mm
C10, C11, C12, C13, C14, C15, C16, C22, C23, C26, C27, C28, C36, C37, C38, C39, C40, C41, C42, C50, C51, C52, C53, C54: 100nf; C_0603_1608Metric
D1, D2: 1N5819; D_SOD-123
D3, D4, D5, D6, D7, D8, D9, D10: LED; LED_D3.0mm
FB1, FB2: Ferrite; R_0603_1608Metric
IC1, IC2, IC4, IC6, IC7, IC9: TL072; SOIC-8_3.9x4.9mm_P1.27mm
IC3, IC5, IC8, IC10: LM358; SOIC-8_3.9x4.9mm_P1.27mm
JP1: EURO_PWR_2x5; PinHeader_2x05_P2.54mm_Vertical
J_CV_IN1, J_CV_IN2, J_CV_IN3, J_CV_IN4: PJ301M-12
J_IN1, J_IN2, J_IN3, J_IN4: PJ301M-12
J_OUT1, J_OUT2, J_OUT3, J_OUT4: PJ301M-12
POT_CV_LEVEL1, POT_CV_LEVEL2, POT_CV_LEVEL3, POT_CV_LEVEL4: B100k; Alpha9mmPot
POT_FEEDBACK1, POT_FEEDBACK2, POT_FEEDBACK3, POT_FEEDBACK4: A100k; Alpha9mmPot
POT_GAIN1, POT_GAIN2, POT_GAIN3, POT_GAIN4: A100k; Alpha9mmPot
POT_IN_DRIVE1, POT_IN_DRIVE2, POT_IN_DRIVE3, POT_IN_DRIVE4: A100k; Alpha9mmPot
R1, R24, R48, R72: 1k; R_0603_1608Metric
R2, R12, R25, R36, R49, R60, R73, R84: 33k; R_0603_1608Metric
R3, R4, R5, R8, R9, R14, R17, R21, R23, R26, R27, R28, R30, R31, R32, R34, R39, R41, R45, R47, R50, R51, R52, R54, R55, R56, R58, R62, R64, R69, R71, R74, R75, R76, R78, R79, R80, R81, R86, R88, R93, R95, R96, R97, R98, R99: 100k; R_0603_1608Metric
R6, R29, R53, R77: 8k2; R_0603_1608Metric
R7: 100R; R_0603_1608Metric
R10, R33, R57, R82: 330R; R_0603_1608Metric
R11, R35, R59, R83: 2k2; R_0603_1608Metric
R13, R37, R61, R85: 750R; R_1210_3225Metric
R15, R16, R38, R40, R63, R66, R87, R89: 1k2; R_0603_1608Metric
R18, R19, R42, R43, R65, R67, R90, R91: 220k; R_0603_1608Metric
R20, R44, R68, R92: 51k; R_0603_1608Metric
R22, R46, R70, R94: 10k; R_0603_1608Metric
SW_DIST1, SW_DIST2, SW_DIST3, SW_DIST4: SW_SPDT; SW_100SP1T1B4M2QE
TRIM_CLEAN1, TRIM_CLEAN2, TRIM_CLEAN3, TRIM_CLEAN4: 100k; Potentiometer_Bourns_3296W_Vertical
TRIM_CV_INIT1, TRIM_CV_INIT2, TRIM_CV_INIT3, TRIM_CV_INIT4: 100k; Potentiometer_Bourns_3296W_Vertical
TRIM_DIST1, TRIM_DIST2, TRIM_DIST3, TRIM_DIST4: 1M; Potentiometer_Bourns_3296W_Vertical
TRIM_PLATE1, TRIM_PLATE2, TRIM_PLATE3, TRIM_PLATE4: 20k; Potentiometer_Bourns_3296W_Vertical
V1, V2, V3, V4: 1J24B; Valve_Mini_Pentode_1j24b

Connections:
+12V: C1.1, C10.1, C11.1, C12.1, C22.1, C23.1, C36.1, C37.1, C38.1, C50.1, C51.1, D3.2 (A), D4.2 (A), D5.2 (A), D6.2 (A), D7.2 (A), D8.2 (A), D9.2 (A), D10.2 (A), FB1.2, IC1.8 (V+), IC2.8 (V+), IC3.8 (V+), IC4.8 (V+), IC5.8 (V+), IC6.8 (V+), IC7.8 (V+), IC8.8 (V+), IC9.8 (V+), IC10.8 (V+), POT_GAIN1.3, POT_GAIN2.3, POT_GAIN3.3, POT_GAIN4.3, R6.1, R29.1, R53.1, R77.1
-12V: C2.2, C7.2, C13.2, C14.2, C15.2, C21.2, C26.2, C27.2, C33.2, C39.2, C40.2, C41.2, C47.2, C52.2, C53.2, FB2.2, IC1.4 (V-), IC2.4 (V-), IC3.4 (V-), IC4.4 (V-), IC5.4 (V-), IC6.4 (V-), IC7.4 (V-), IC8.4 (V-), IC9.4 (V-), IC10.4 (V-), TRIM_CLEAN1.1, TRIM_CLEAN1.2, TRIM_CLEAN2.1, TRIM_CLEAN2.2, TRIM_CLEAN3.1, TRIM_CLEAN3.2, TRIM_CLEAN4.1, TRIM_CLEAN4.2, TRIM_CV_INIT1.3, TRIM_CV_INIT2.3, TRIM_CV_INIT3.3, TRIM_CV_INIT4.3, V1.2, V1.4, V2.2, V2.4, V3.2, V3.4, V4.2, V4.4
GND: C1.2, C2.1, C7.1, C10.2, C11.2, C12.2, C13.1, C14.1, C15.1, C16.2, C21.1, C22.2, C23.2, C26.1, C27.1, C28.2, C33.1, C36.2, C37.2, C38.2, C39.1, C40.1, C41.1, C42.2, C47.1, C50.2, C51.2, C52.1, C53.1, C54.2, IC1.3 (+), IC3.3 (+), IC3.5 (+), IC4.3 (+), IC5.3 (+), IC5.5 (+), IC6.3 (+), IC8.3 (+), IC8.5 (+), IC9.3 (+), IC10.3 (+), IC10.5 (+), JP1.3 (GND), JP1.4 (GND), JP1.5 (GND), JP1.6 (GND), JP1.7 (GND), JP1.8 (GND), J_CV_IN1.1, J_CV_IN1.2, J_CV_IN2.1, J_CV_IN2.2, J_CV_IN3.1, J_CV_IN3.2, J_CV_IN4.1, J_CV_IN4.2, J_IN1.1, J_IN1.2, J_IN2.1, J_IN2.2, J_IN3.1, J_IN3.2, J_IN4.1, J_IN4.2, J_OUT1.1, J_OUT2.1, J_OUT3.1, J_OUT4.1, POT_CV_LEVEL1.1, POT_CV_LEVEL2.1, POT_CV_LEVEL3.1, POT_CV_LEVEL4.1, POT_FEEDBACK1.1, POT_FEEDBACK2.1, POT_FEEDBACK3.1, POT_FEEDBACK4.1, POT_GAIN1.1, POT_GAIN2.1, POT_GAIN3.1, POT_GAIN4.1, POT_IN_DRIVE1.1, POT_IN_DRIVE2.1, POT_IN_DRIVE3.1, POT_IN_DRIVE4.1, R2.1, R12.2, R13.2, R15.1, R16.2, R25.1, R36.2, R37.2, R38.1, R40.2, R49.1, R60.2, R61.2, R63.1, R66.2, R73.1, R84.2, R85.2, R87.1, R89.2, R96.2, R97.2, R98.2, R99.2, TRIM_CV_INIT1.1, TRIM_CV_INIT2.1, TRIM_CV_INIT3.1, TRIM_CV_INIT4.1, TRIM_DIST1.1, TRIM_DIST1.2, TRIM_DIST2.1, TRIM_DIST2.2, TRIM_DIST3.1, TRIM_DIST3.2, TRIM_DIST4.1, TRIM_DIST4.2, V1.3, V2.3, V3.3, V4.3
unnamed: C3.1, IC1.1, R5.2, R11.1
unnamed: C3.2, IC1.2 (-), R4.2, R5.1, R8.2
unnamed: C4.1, IC1.6 (-), R2.2, R3.1
unnamed: C4.2, IC1.7, R1.1, R3.2, R9.2
unnamed: C5.1, TRIM_PLATE1.2, TRIM_PLATE1.3, V1.7 (TC)
unnamed: C5.2, IC1.5 (+), R12.1
unnamed: C6.1, R11.2
unnamed: C6.2, SW_DIST1.2 (B), V1.6
unnamed: C8.1, IC3.6 (-), R18.1, R23.2
unnamed: C8.2, IC3.7, R18.2, R21.1
unnamed: C9.1, IC3.2 (-), R14.1, R17.1, R19.1, R20.2
unnamed: C9.2, IC3.1, R19.2, R22.1
unnamed: C16.1, R22.2, R23.1
unnamed: C17.1, IC4.1, R28.2, R35.1
unnamed: C17.2, IC4.2 (-), R27.2, R28.1, R32.2
unnamed: C18.1, IC4.6 (-), R25.2, R26.1
unnamed: C18.2, IC4.7, R24.1, R26.2, R34.2
unnamed: C19.1, TRIM_PLATE2.2, TRIM_PLATE2.3, V2.7 (TC)
unnamed: C19.2, IC4.5 (+), R36.1
unnamed: C20.1, R35.2
unnamed: C20.2, SW_DIST2.2 (B), V2.6
unnamed: C24.1, IC5.6 (-), R42.1, R47.2
unnamed: C24.2, IC5.7, R42.2, R45.1
unnamed: C25.1, IC5.2 (-), R39.1, R41.1, R43.1, R44.2
unnamed: C25.2, IC5.1, R43.2, R46.1
unnamed: C28.1, R46.2, R47.1
unnamed: C29.1, IC6.1, R52.2, R59.1
unnamed: C29.2, IC6.2 (-), R51.2, R52.1, R56.2
unnamed: C30.1, IC6.6 (-), R49.2, R50.1
unnamed: C30.2, IC6.7, R48.1, R50.2, R58.2
unnamed: C31.1, TRIM_PLATE3.2, TRIM_PLATE3.3, V3.7 (TC)
unnamed: C31.2, IC6.5 (+), R60.1
unnamed: C32.1, R59.2
unnamed: C32.2, SW_DIST3.2 (B), V3.6
unnamed: C34.1, IC8.6 (-), R65.1, R71.2
unnamed: C34.2, IC8.7, R65.2, R69.1
unnamed: C35.1, IC8.2 (-), R62.1, R64.1, R67.1, R68.2
unnamed: C35.2, IC8.1, R67.2, R70.1
unnamed: C42.1, R70.2, R71.1
unnamed: C43.1, IC9.1, R76.2, R83.1
unnamed: C43.2, IC9.2 (-), R75.2, R76.1, R80.2
unnamed: C44.1, IC9.6 (-), R73.2, R74.1
unnamed: C44.2, IC9.7, R72.1, R74.2, R81.2
unnamed: C45.1, TRIM_PLATE4.2, TRIM_PLATE4.3, V4.7 (TC)
unnamed: C45.2, IC9.5 (+), R84.1
unnamed: C46.1, R83.2
unnamed: C46.2, SW_DIST4.2 (B), V4.6
unnamed: C48.1, IC10.6 (-), R90.1, R95.2
unnamed: C48.2, IC10.7, R90.2, R93.1
unnamed: C49.1, IC10.2 (-), R86.1, R88.1, R91.1, R92.2
unnamed: C49.2, IC10.1, R91.2, R94.1
unnamed: C54.1, R94.2, R95.1
unnamed: D1.1 (K), FB1.1
unnamed: D1.2 (A), JP1.1 (+12V), JP1.2 (+12V)
unnamed: D2.1 (K), JP1.9 (-12V), JP1.10 (-12V)
unnamed: D2.2 (A), FB2.1
unnamed: D3.1 (K), R15.2
unnamed: D4.1 (K), R16.1
unnamed: D5.1 (K), R38.2
unnamed: D6.1 (K), R40.1
unnamed: D7.1 (K), R63.2
unnamed: D8.1 (K), R66.1
unnamed: D9.1 (K), R87.2
unnamed: D10.1 (K), R89.1
unnamed: IC2.1, R7.1, R10.1
unnamed: IC2.2 (-), R7.2, R96.1
unnamed: IC2.3 (+), R9.1
unnamed: IC2.5 (+), R30.1, R34.1
unnamed: IC2.6 (-), R31.2, R97.1
unnamed: IC2.7, R31.1, R33.1
unnamed: IC7.1, R55.1, R57.1
unnamed: IC7.2 (-), R55.2, R98.1
unnamed: IC7.3 (+), R54.1, R58.1
unnamed: IC7.5 (+), R79.1, R81.1
unnamed: IC7.6 (-), R78.2, R99.1
unnamed: IC7.7, R78.1, R82.1
unnamed: J_CV_IN1.3, POT_CV_LEVEL1.3
unnamed: J_CV_IN2.3, POT_CV_LEVEL2.3
unnamed: J_CV_IN3.3, POT_CV_LEVEL3.3
unnamed: J_CV_IN4.3, POT_CV_LEVEL4.3
unnamed: J_IN1.3, POT_IN_DRIVE1.3
unnamed: J_IN2.3, POT_IN_DRIVE2.3
unnamed: J_IN3.3, POT_IN_DRIVE3.3
unnamed: J_IN4.3, POT_IN_DRIVE4.3
unnamed: J_OUT1.2, R30.2
unnamed: J_OUT1.3, R10.2
unnamed: J_OUT2.2, R54.2
unnamed: J_OUT2.3, R33.2
unnamed: J_OUT3.2, R79.2
unnamed: J_OUT3.3, R57.2
unnamed: J_OUT4.3, R82.2
unnamed: POT_CV_LEVEL1.2, R20.1
unnamed: POT_CV_LEVEL2.2, R44.1
unnamed: POT_CV_LEVEL3.2, R68.1
unnamed: POT_CV_LEVEL4.2, R92.1
unnamed: POT_FEEDBACK1.2, R4.1
unnamed: POT_FEEDBACK1.3, R1.2
unnamed: POT_FEEDBACK2.2, R27.1
unnamed: POT_FEEDBACK2.3, R24.2
unnamed: POT_FEEDBACK3.2, R51.1
unnamed: POT_FEEDBACK3.3, R48.2
unnamed: POT_FEEDBACK4.2, R75.1
unnamed: POT_FEEDBACK4.3, R72.2
unnamed: POT_GAIN1.2, R17.2
unnamed: POT_GAIN2.2, R41.2
unnamed: POT_GAIN3.2, R64.2
unnamed: POT_GAIN4.2, R88.2
unnamed: POT_IN_DRIVE1.2, R8.1
unnamed: POT_IN_DRIVE2.2, R32.1
unnamed: POT_IN_DRIVE3.2, R56.1
unnamed: POT_IN_DRIVE4.2, R80.1
unnamed: R6.2, TRIM_PLATE1.1
unnamed: R13.1, V1.1
unnamed: R14.2, TRIM_CV_INIT1.2
unnamed: R21.2, V1.5
unnamed: R29.2, TRIM_PLATE2.1
unnamed: R37.1, V2.1
unnamed: R39.2, TRIM_CV_INIT2.2
unnamed: R45.2, V2.5
unnamed: R53.2, TRIM_PLATE3.1
unnamed: R61.1, V3.1
unnamed: R62.2, TRIM_CV_INIT3.2
unnamed: R69.2, V3.5
unnamed: R77.2, TRIM_PLATE4.1
unnamed: R85.1, V4.1
unnamed: R86.2, TRIM_CV_INIT4.2
unnamed: R93.2, V4.5
unnamed: SW_DIST1.1 (A), TRIM_DIST1.3
unnamed: SW_DIST1.3 (C), TRIM_CLEAN1.3
unnamed: SW_DIST2.1 (A), TRIM_DIST2.3
unnamed: SW_DIST2.3 (C), TRIM_CLEAN2.3
unnamed: SW_DIST3.1 (A), TRIM_DIST3.3
unnamed: SW_DIST3.3 (C), TRIM_CLEAN3.3
unnamed: SW_DIST4.1 (A), TRIM_DIST4.3
unnamed: SW_DIST4.3 (C), TRIM_CLEAN4.3

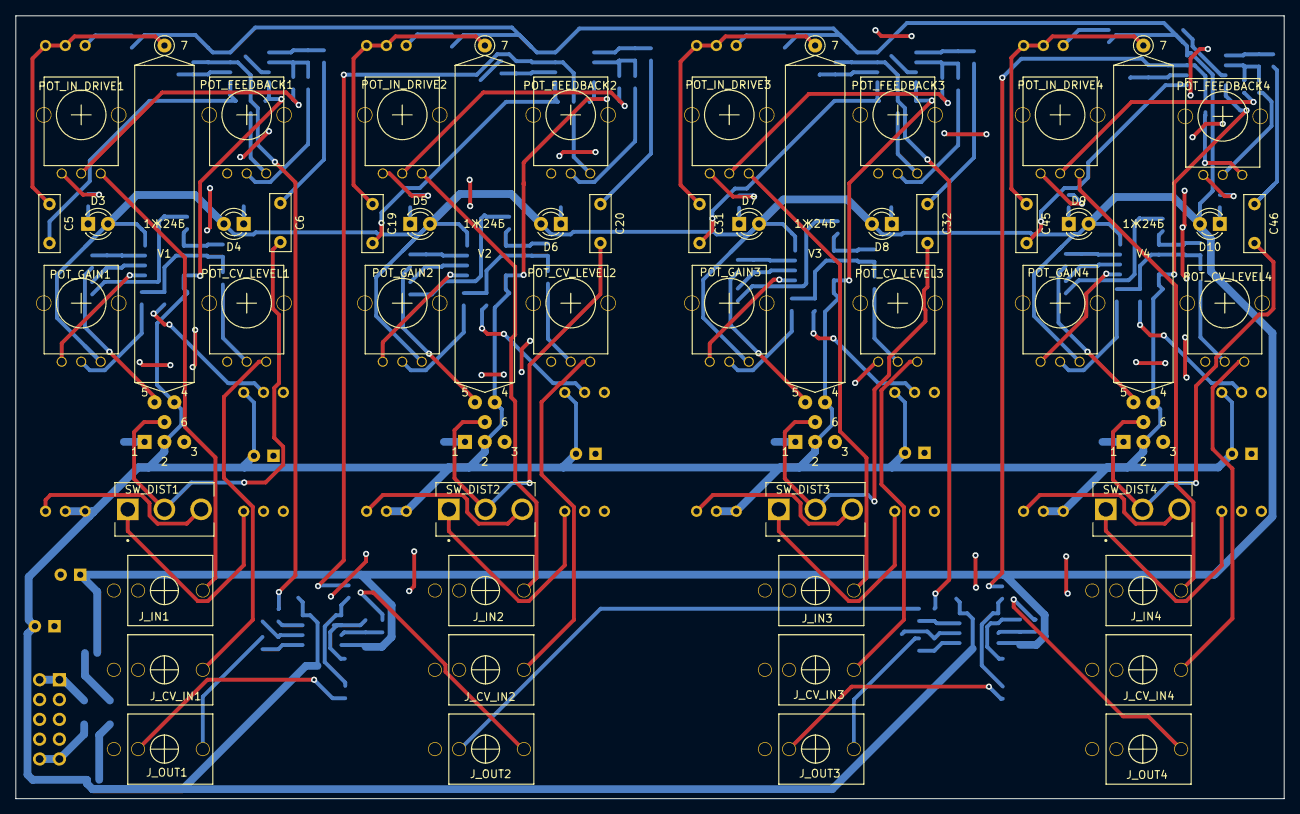
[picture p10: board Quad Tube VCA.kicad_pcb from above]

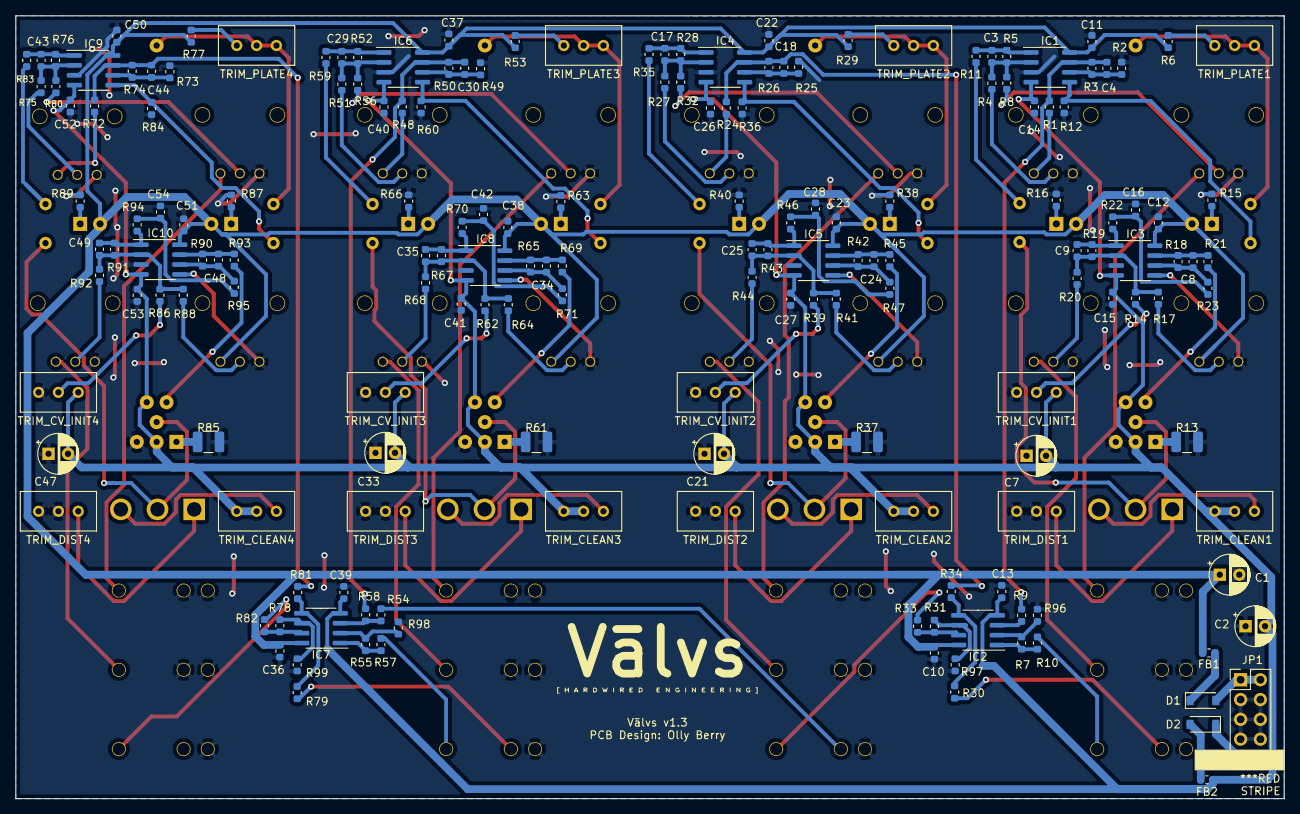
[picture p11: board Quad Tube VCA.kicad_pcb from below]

Board: 2 copper layers, 162.6 x 100.3 mm, 228 parts (176 on the bottom side), 138 nets.

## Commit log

2021-12-31 initial v0.1 commit
    [Quad Tube VCA.kicad_pcb, Quad Tube VCA.sch]
2022-01-01 power and vca1 routed
    [Quad Tube VCA.kicad_pcb]
2022-01-01 changes footprints for pots/jacks
    [Quad Tube VCA.kicad_pcb, Quad Tube VCA.sch]
2022-01-01 upadtes 3d models, makes more space at pcb edges
    [Quad Tube VCA.kicad_pcb]
2022-01-01 updates layout
    [Quad Tube VCA.kicad_pcb]
2022-01-01 starts work on power traces
    [Quad Tube VCA.kicad_pcb]
2022-01-01 routes power traces
    [Quad Tube VCA.kicad_pcb]
2022-01-01 routes nets for vca4 op amps
    [Quad Tube VCA.kicad_pcb]
2022-01-01 routes nets for remaining op amps
    [Quad Tube VCA.kicad_pcb]
2022-01-01 fixes ground nets
    [Quad Tube VCA.kicad_pcb]
2022-01-01 hooks up all nets
    [Quad Tube VCA.kicad_pcb]
2022-01-01 fixes gnd in op amp section
    [Quad Tube VCA.kicad_pcb]
2022-01-01 fixes gnd everywhere
    [Quad Tube VCA.kicad_pcb]
2022-01-01 avoids jack centers
    [Quad Tube VCA.kicad_pcb]
2022-01-01 updates silkscreen
    [Quad Tube VCA.kicad_pcb]
2022-01-02 adds v0.3 gerbers
    [Quad Tube VCA-B_Cu.gbl, Quad Tube VCA-B_Mask.gbs, Quad Tube VCA-B_Paste.gbp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]
2022-01-02 adds v0.3 panel
    [Quad Tube VCA Panel.kicad_pcb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]
2022-01-02 adds FreeCAD model
    [Valvs 3D model.FCStd]
2022-01-02 fixes pot placement issue
    [Quad Tube VCA Panel.kicad_pcb, Quad Tube VCA.kicad_pcb]
2022-01-02 updates project structure
    [Quad Tube VCA-B_Cu.gbl, Quad Tube VCA-B_Mask.gbs, Quad Tube VCA-B_Paste.gbp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]
2022-01-03 tightens up panel design
    [Quad Tube VCA Panel.kicad_pcb, Quad Tube VCA.kicad_pcb]
2022-01-15 adds v0.5 gerbers
    [Quad Tube VCA-B_Cu.gbl, Quad Tube VCA-B_Mask.gbs, Quad Tube VCA-B_Paste.gbp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]
2022-01-16 adds summing mixers to outputs
    [Quad Tube VCA.kicad_pcb, Quad Tube VCA.sch]
2022-01-16 adds mixer parts to pcb - needs re-routing
    [Quad Tube VCA.kicad_pcb]
2022-01-16 cleans up refs
    [Quad Tube VCA.kicad_pcb]
2022-01-16 updates footprints/models
    [Quad Tube VCA.kicad_pcb]
2022-01-16 updates positions
    [Quad Tube VCA.kicad_pcb]
2022-01-16 tightens up positions
    [Quad Tube VCA.kicad_pcb]
2022-01-16 updates footprints in schematic
    [Quad Tube VCA.kicad_pcb, Quad Tube VCA.sch]
2022-01-16 syncs pcb/schem
    [Quad Tube VCA.kicad_pcb]
2022-01-16 first GND pour
    [Quad Tube VCA.kicad_pcb]
2022-01-16 +12V net
    [Quad Tube VCA.kicad_pcb]
2022-01-16 -12V net
    [Quad Tube VCA.kicad_pcb]
2022-01-16 connects easy nets
    [Quad Tube VCA.kicad_pcb]
2022-01-16 connects some trickier nets
    [Quad Tube VCA.kicad_pcb]
2022-01-17 tightens gnd pour clearance
    [Quad Tube VCA.kicad_pcb]
2022-01-17 everything connected
    [Quad Tube VCA.kicad_pcb]
2022-01-17 syncs with pcb
    [Quad Tube VCA.kicad_pcb]
2022-01-17 updates panel
    [Quad Tube VCA Panel.kicad_pcb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]
2022-01-18 tightens panel positions
    [Quad Tube VCA Panel.kicad_pcb, Quad Tube VCA.kicad_pcb]
2022-01-18 adds copper to panel
    [Quad Tube VCA Panel.kicad_pcb]
2022-01-18 text positions
    [Quad Tube VCA Panel.kicad_pcb]
2022-01-18 adds v0.6 gerbers
    [Quad Tube VCA Panel-B_Cu.gbl, Quad Tube VCA Panel-B_Mask.gbs, Quad Tube VCA Panel-B_Paste.gbp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]
2022-01-18 tweaks panel pcb layers
    [Quad Tube VCA Panel-B_Cu.gbl, Quad Tube VCA Panel-B_Mask.gbs, Quad Tube VCA Panel-B_Paste.gbp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]
2022-01-19 adds copper to front of panel
    [Quad Tube VCA Panel.kicad_pcb]
2022-01-19 updates v0.6 gerbers
    [Quad Tube VCA Panel-B_Cu.gbl, Quad Tube VCA Panel-B_Mask.gbs, Quad Tube VCA Panel-B_Paste.gbp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]
2022-01-20 updates panel copper/silkscreen
    [Quad Tube VCA Panel.kicad_pcb]
2022-01-20 updates panel copper/silkscreen again
    [Quad Tube VCA Panel.kicad_pcb]
2022-01-22 flips pots on schematic
    [Quad Tube VCA.sch]
2022-01-22 reroutes pots on PCB
    [Quad Tube VCA Panel.kicad_pcb, Quad Tube VCA.kicad_pcb]
2022-01-24 adds new images
    [Quad Tube VCA Panel.kicad_pcb]
2022-01-24 updates PCB silkscreen
    [Quad Tube VCA.kicad_pcb]
2022-01-24 adds keepouts for jack tips
    [Quad Tube VCA.kicad_pcb]
2022-01-24 lays some long traces
    [Quad Tube VCA.kicad_pcb]
2022-01-24 connects -12V
    [Quad Tube VCA.kicad_pcb]
2022-01-24 connects +12V
    [Quad Tube VCA.kicad_pcb]
2022-01-24 op amp traces [WIP]
    [Quad Tube VCA.kicad_pcb]
2022-01-24 updates panel fonts
    [Quad Tube VCA Panel.kicad_pcb, Quad Tube VCA.kicad_pcb]
2022-01-24 all connected
    [Quad Tube VCA.kicad_pcb]
2022-01-24 updates gerbers
    [Quad Tube VCA Panel-B_Cu.gbl, Quad Tube VCA Panel-B_Mask.gbs, Quad Tube VCA Panel-B_Paste.gbp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]
2022-01-24 removes unnecessary files
    [Valvs 0.5 3D model.FCStd, Valvs 3D model.FCStd]
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2022-01-25 updates dir structure
    [Quad Tube VCA Panel.kicad_pcb, Quad Tube VCA.kicad_pcb, Quad Tube VCA.sch]
2022-01-25 updates panel drawings
    [Quad Tube VCA Panel-B_Cu.gbl, Quad Tube VCA Panel-B_Mask.gbs, Quad Tube VCA Panel-B_Paste.gbp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]
2022-01-26 adds reverse power protection diodes
    [Quad Tube VCA-B_Cu.gbl, Quad Tube VCA-B_Mask.gbs, Quad Tube VCA-B_Paste.gbp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]
2022-01-26 removes leds from cathode/signal path
    [Quad Tube VCA.kicad_pcb, Quad Tube VCA.sch]
2022-01-27 updates annotations - need to regen BOM
    [Quad Tube VCA.kicad_pcb, Quad Tube VCA.sch]
2022-01-27 updates GND
    [Quad Tube VCA.kicad_pcb]
2022-01-27 updates BOM
    [Quad Tube VCA.kicad_pcb]
2022-01-28 removes leds from signal path
    [Quad Tube VCA Panel-B_Cu.gbl, Quad Tube VCA Panel-B_Mask.gbs, Quad Tube VCA Panel-B_Paste.gbp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]
2022-02-08 enlarges panel holes for switches
    [Quad Tube VCA Panel-B_Cu.gbl, Quad Tube VCA Panel-B_Mask.gbs, Quad Tube VCA Panel-B_Paste.gbp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]
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2022-02-23 fix: #3 updates ref. on bom
2022-03-04 adds inverting buffers, new layout
    [Quad Tube VCA.kicad_pcb, Quad Tube VCA.sch]
2022-03-04 routes new layout
    [Quad Tube VCA.kicad_pcb]
2022-03-04 fix: #4 adds new gerbers
    [Quad Tube VCA-B_Cu.gbl, Quad Tube VCA-B_Mask.gbs, Quad Tube VCA-B_Paste.gbp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]
2022-03-04 adds new BOM/pos
    [Quad Tube VCA BOM.csv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]
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2022-03-15 updates feedback resistor value for vca1
    [Quad Tube VCA BOM.csv, Quad Tube VCA.kicad_pcb, Quad Tube VCA.sch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]
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
